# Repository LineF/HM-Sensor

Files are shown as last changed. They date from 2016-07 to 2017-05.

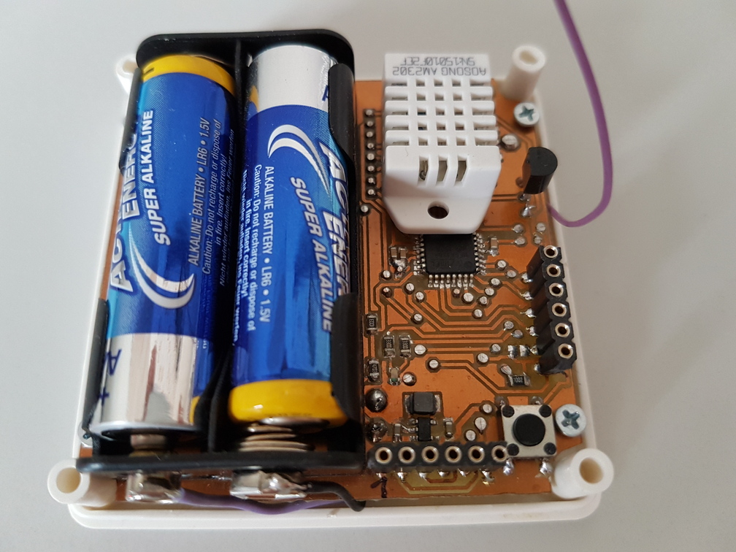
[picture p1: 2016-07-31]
Schematic/Eagle/Vorderseite.jpg

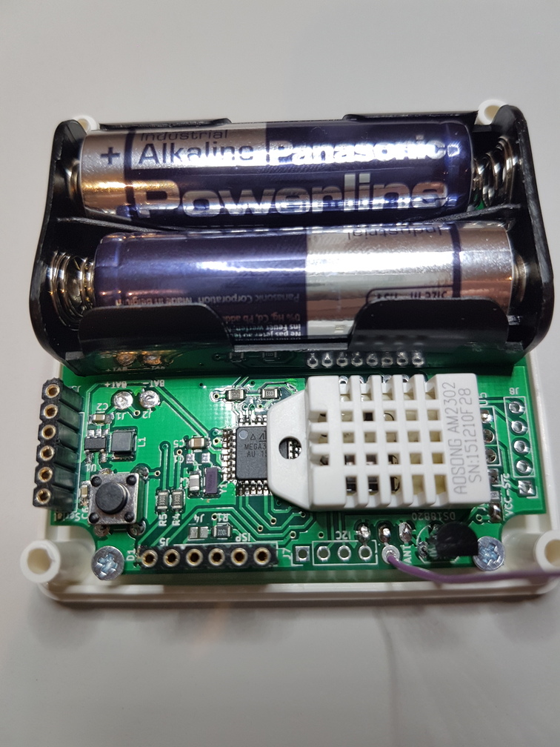
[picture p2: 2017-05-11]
Schematic/KiCad/Vorderseite fertig.jpg

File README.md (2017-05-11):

# HM-Sensor

Nachbau des "Universalsensors" von Dirk, allerdings mit anderen Sensoren.

Zum Einsatz kommen die günstigen DHT-22 und/oder DS18B20 Sensoren. 
Alternativ kann noch ein SHT-21 (sehr kompakt und genau) verwendet werden (Code hierfür allerdings nicht vorhanden)

Der Sensor verwendet als Untermodul die NewAskSin Library von Trilu. Diese habe ich für meine Bedürfnisse etwas angepaßt, wird aber zur Zeit regelmäßig mit Trilus Code aktualisiert.

**Anpassungen:**

 - Erweiterung für WeatherSensor Messages
 - weitere Verbesserungen beim Energieverbrauch
 - Stabilität beim Peering mit HM-CC-RT-DN verbessert
 - Einbau eines 32KHz Uhrenquarzes möglich - damit weitere Verbesserung der Übertragungsgenauigkeit zu einem HM-CC-RT-DN und weitere Reduktion des Stromverbrauchs
 - LED beim Senden kann abgeschaltet werden
 - OSCCAL-Register des Atmel kann remote eingestellt werden (damit kann auch ohne Quarz eine gute Genauigkeit der Taktfrequenz erreicht werden)
 - Automatische Watchdog-Kalibrierung
 - Serielle Debug-Ausgabe auf "flush" umgestellt; damit entfallen die teilweise eingebauten schlecht kalkulierbaren delays
 - Batteriemessgenauigkeit auf 1/100V erhöht (ich mag's halt genau)
 - HAVE_DATA Message-Verarbeitung: damit nimmt der Sensor auch ohne Drücken des Config-Buttons Befehle von der Zentrale bei der nächsten Temperaturübermittlung an
 - der eine oder andere Fix (teilweise von Trilu bereits eingebaut)

Schaltplan, Layout und Belichtungsplan gibt's im Unterordner Schematic.
Die erste Version wurde mit Eagle erstellt (Unterordner Eagle)
Da ich meine Platinen selber ätze, habe ich hier auf doppelseitiges Layout verzichtet - es gibt dafür ein paar Drahtbrücken.

Die zweite Version wurde mit KiCad erstellt und dann bei einem professionellen Fertiger gefertigt (Unterordner Kicad).
Da gibts auch die entsprechenden Bilder.

Achtung:
Die aktuelle Version ab Mitte Mai 2017 hat statt GDO0 jetzt GDO2 verbunden (Fehler beim Erstellen des Schaltplans).
Dies wurde aber im Communication-Modul bei den Parametern IOCFG0 und IOCFG2 entsprechend berücksichtigt.

Als Sendemodul kommt ein CC1101 auf einem günstigen Breakout-Board aus China zum Einsatz.

Entwicklungsumgebung: Atmel Studio 7.0

Der Branch "dev" ist mein aktueller Entwicklungszweig - die Version kann evtl. fehlerhaft oder gar nicht compilierbar sein.
Im Zweifelsfall bitte die Releases verwenden.

Das Release 2.0 ist das letzte stabile und basiert auf der neuen C++ Lib von Trilu (vielen Dank dafür!)

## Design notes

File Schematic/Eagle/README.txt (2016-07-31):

Achtung:

Die Layout-Files wurden nur für die eigene Platinenherstellung verwendet!
(einseitige Platine, viele Brücken)

Vor der Verwendung bei einem professionellen Platinenhersteller bitte
unbedingt Layout nochmals überprüfen (Lochdurchmesser, Abstände, etc...)

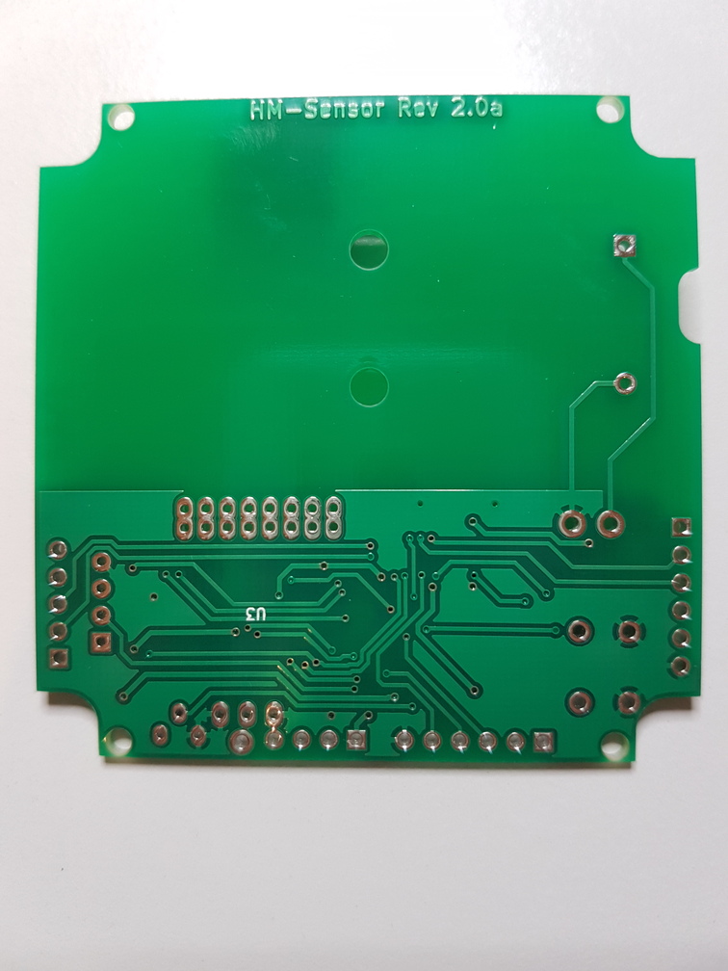
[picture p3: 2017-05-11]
Schematic/KiCad/Platine Rückseite.jpg

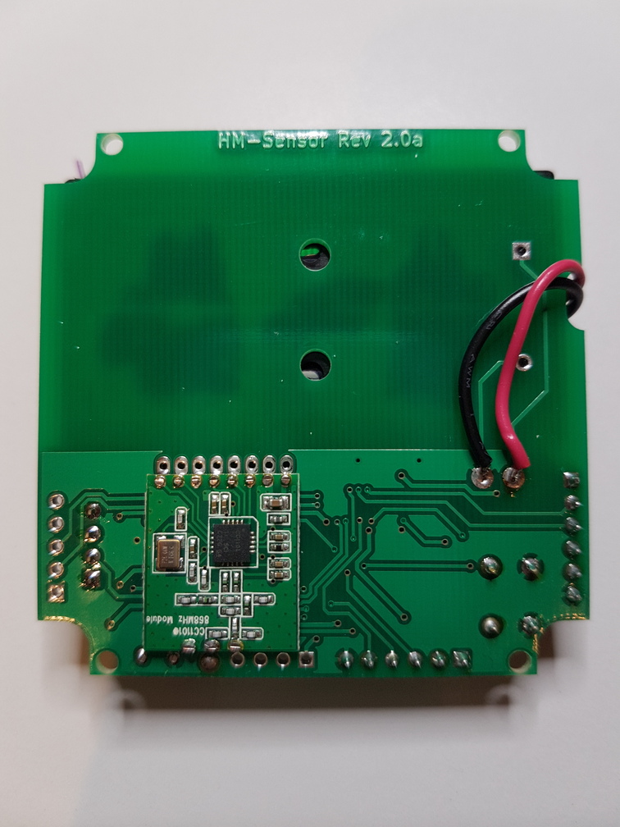
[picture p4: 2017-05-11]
Schematic/KiCad/Rückseite fertig.jpg

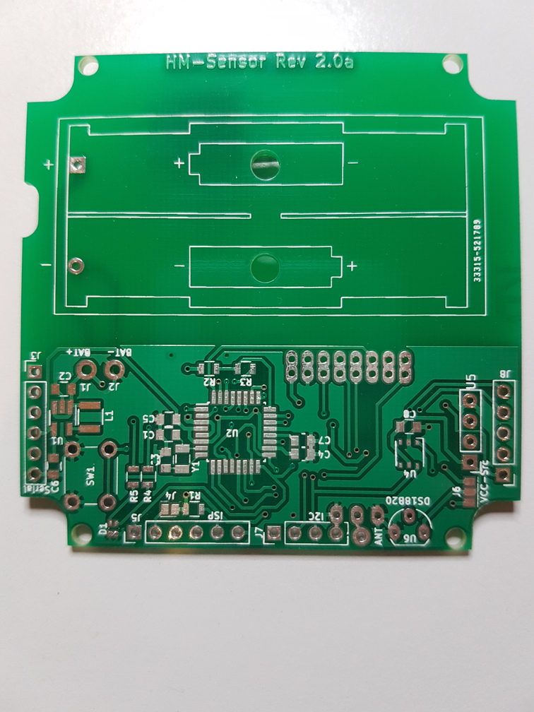
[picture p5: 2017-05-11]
Schematic/KiCad/Platine Vorderseite.jpg

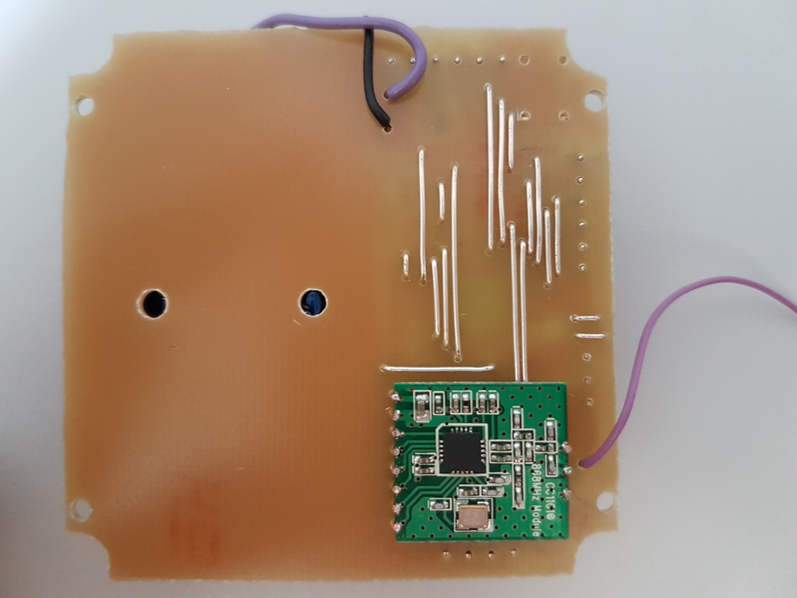
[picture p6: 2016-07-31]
Schematic/Eagle/Rückseite.jpg

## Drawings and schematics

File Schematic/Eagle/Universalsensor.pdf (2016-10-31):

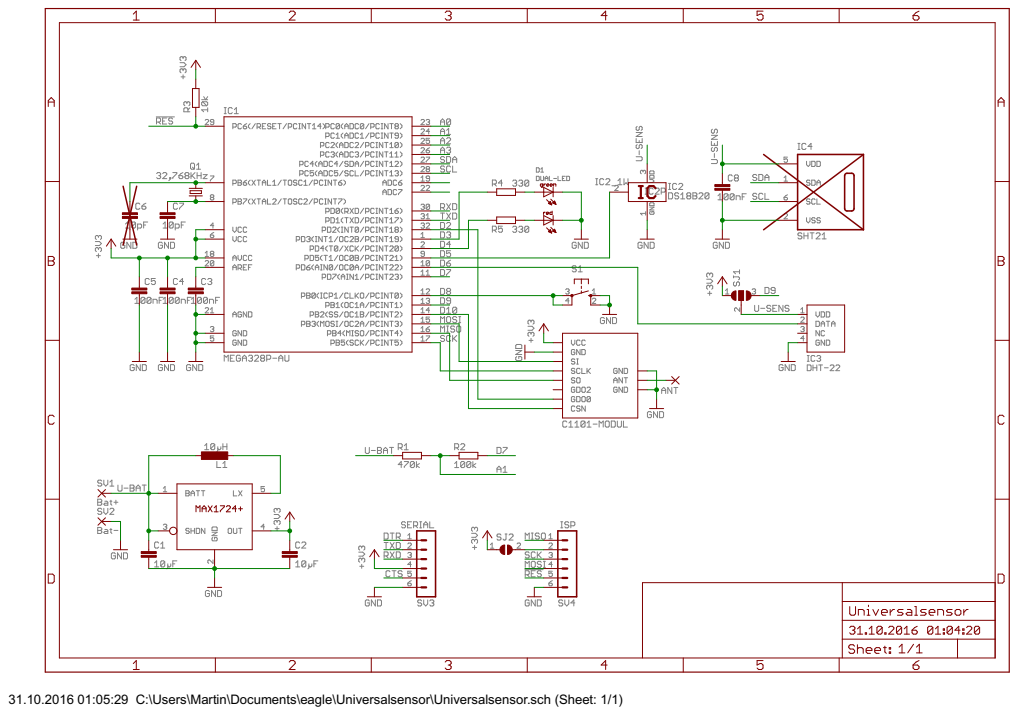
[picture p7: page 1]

31.10.2016 01:05:29 C:\Users\Martin\Documents\eagle\Universalsensor\Universalsensor.sch (Sheet: 1/1)

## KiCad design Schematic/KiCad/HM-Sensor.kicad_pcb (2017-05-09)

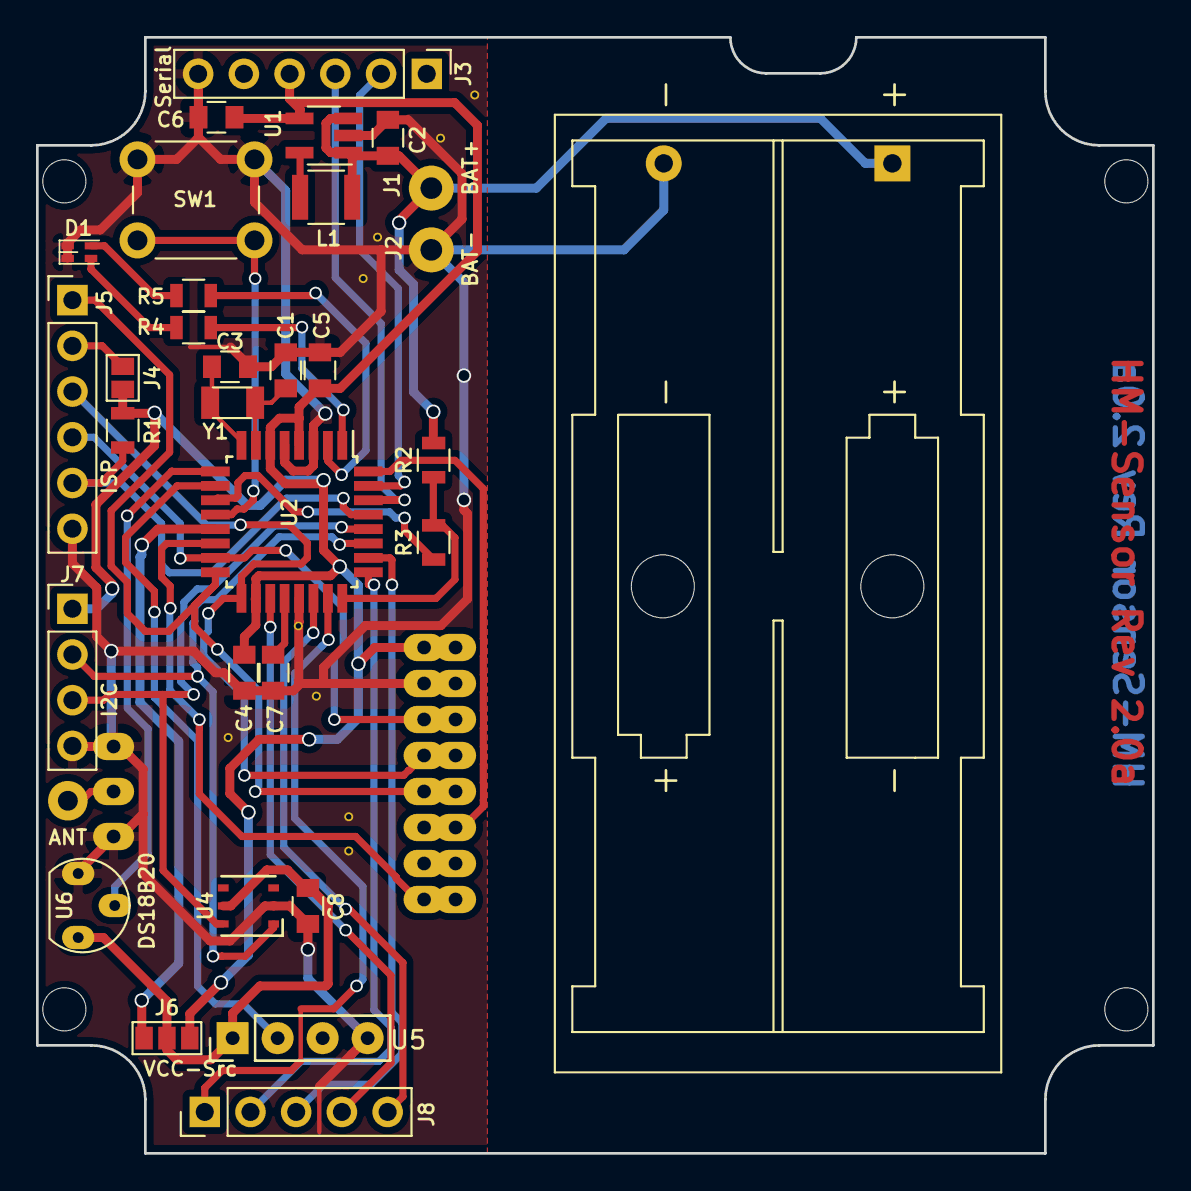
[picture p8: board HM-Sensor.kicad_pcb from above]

Board: 2 copper layers, 62.0 x 62.0 mm, 37 parts (1 on the bottom side), 35 nets.

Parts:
ANT: SolderWirePad_single_1-2mmDrill
C1, C3: 10pF; C_0805
C2, C6: 10uF; C_0805
C4, C5, C7, C8: 100nF; C_0805
D1: LED_Dual_AACC; LED-Dual-SMD-0603
H1, H2, H3, H4: MountingHole_2.5mm
J1: BAT+; SolderWirePad_single_1-2mmDrill
J2: BAT-; SolderWirePad_single_1-2mmDrill
J3: Serial; Pin_Header_Straight_1x06_Pitch2.54mm
J4: GS2
J5: ISP; Pin_Header_Straight_1x06_Pitch2.54mm
J6: VCC-Src; GS3
J7: I2C; Pin_Header_Straight_1x04_Pitch2.54mm
J8: A0-A7; Pin_Header_Straight_1x05_Pitch2.54mm
L1: 10uH; L_1210
R1: 10k; R_0805
R2: 470k; R_0805
R3: 100k; R_0805
R4, R5: 330; R_0805
REF1: Keystone_2468_2xAAA
SW1: SW_Push; SW_PUSH_6mm_h5mm
U1: MAX1724+; SOT-23-5_HandSoldering
U2: ATMEGA328P-AU; TQFP-32_7x7mm_Pitch0.8mm
U3: CC1101-Modul
U4: SHT2x; SHT21
U5: DHT22; DHT-22
U6: DS18B20; TO-92_Molded_Oval
Y1: 32.768kHz; Crystal_32KHz_CC7V_T1A

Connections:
+3V3: C4.1, C5.1, C6.1, J3.4, J4.2, J6.1, J7.1, R1.1, U1.4, U2.4, U2.6, U2.18, U3.1
//RES: J5.5, R1.2, U2.29
/A0: J8.1, U2.23
/A1: R2.1, R3.2, U2.24
/A2: J8.2, U2.25
/A3: J8.3, U2.26
/A6: J8.4, U2.19
/A7: J8.5, U2.22
/B0: SW1.1, U2.12
/B1: J6.3, U2.13
/B2: U2.14, U3.8
/D2: U2.32, U3.6
/D3: R4.2, U2.1
/D4: R5.2, U2.2
/D5: U2.9, U6.2
/D6: U2.10, U5.2
/D7: R3.1, U2.11
/MISO: J5.1, U2.16, U3.5
/MOSI: J5.4, U2.15, U3.3
/RXD: J3.3, U2.30
/SCK: J5.3, U2.17, U3.4
/SCL: J7.3, U2.28, U4.6
/SDA: J7.2, U2.27, U4.1
/TXD: J3.2, U2.31
/U-BAT: C2.1, J1.1, L1.2, R2.2, REF1.1, U1.1, U1.3
/U-Sens: C8.1, J6.2, U4.5, U5.1, U6.3
/XTAL1: C1.1, U2.7, Y1.2
/XTAL2: C3.1, U2.8, Y1.1
GND: C1.2, C2.2, C3.2, C4.2, C5.2, C6.2, C7.2, C8.2, D1.3, D1.4, J2.1, J3.6, J5.6, J7.4, REF1.2, SW1.2, U1.2, U2.3, U2.5, U2.21, U3.2, U3.9, U3.11, U4.2, U5.4, U6.1
unnamed: ANT.1, U3.10
unnamed: C7.1, U2.20
unnamed: D1.1, R4.1
unnamed: D1.2, R5.1
unnamed: J4.1, J5.2
unnamed: L1.1, U1.5

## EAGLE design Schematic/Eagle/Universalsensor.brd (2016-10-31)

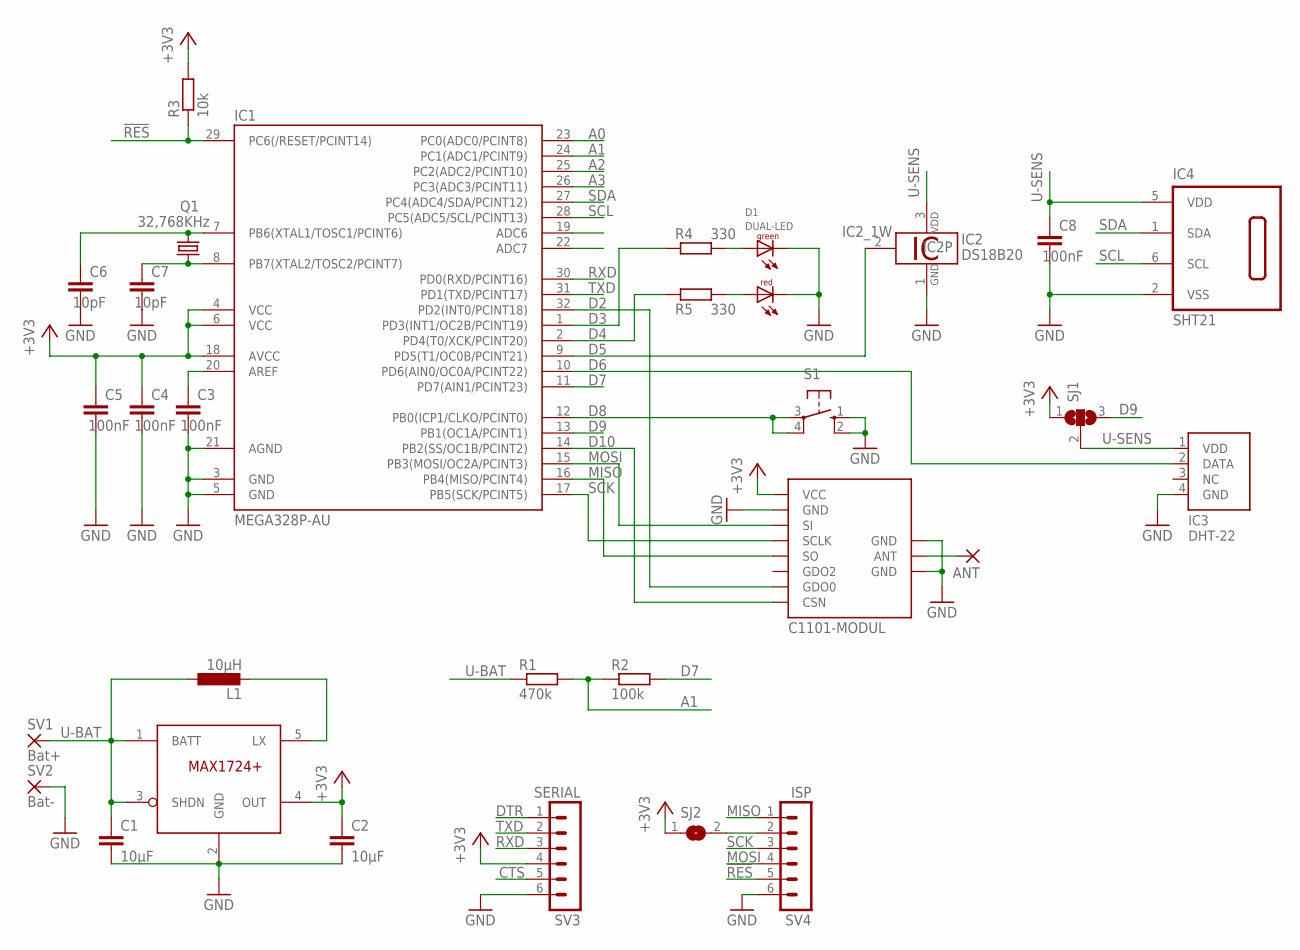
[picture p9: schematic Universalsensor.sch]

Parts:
ANT: 2,54/1,1
C1, C2: 10µF; C0603K
C3, C4, C5, C8: 100nF; C0603K
C6, C7: 10pF; C0603K
D1: DUAL-LED
IC1: MEGA328P-AU; TQFP32-08
IC2: DS18B20; TO92-
IC3: DHT-22; DHT-22-L
IC4: SHT21; DFN6/SHT
IC5: MAX1724; SOT23-5L
L1: 10µH; L3230M
Q1: 32,768KHz; OSCILLATOR_SMD
R1: 470k; R0805
R2: 100k; R0805
R3: 10k; R0805
R4, R5: 330; R0805
S1: 10-XX; B3F-10XX
SJ1: SJ2W; SJ_2
SJ2: SJ
SV1: Bat+; 2,54/1,1
SV2: Bat-; 2,54/1,1
SV3: SERIAL; MA06-1
SV4: ISP; MA06-1
U$2: C1101-MODUL; CC1101-MODUL

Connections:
!RES: IC1.29 (PC6(/RESET/PCINT14)), R3.1, SV4.5
+3V3: C2.1, C4.1, C5.1, IC1.4 (VCC), IC1.6 (VCC), IC1.18 (AVCC), IC5.4 (OUT), R3.2, SJ1.1, SJ2.1, SV3.4, U$2.VCC
A0: IC1.23 (PC0(ADC0/PCINT8))
A1: IC1.24 (PC1(ADC1/PCINT9)), R1.2, R2.1
A2: IC1.25 (PC2(ADC2/PCINT10))
A3: IC1.26 (PC3(ADC3/PCINT11))
CTS: SV3.5
D2: IC1.32 (PD2(INT0/PCINT18)), U$2.GDO0
D3: IC1.1 (PD3(INT1/OC2B/PCINT19)), R4.2
D4: IC1.2 (PD4(T0/XCK/PCINT20)), R5.2
D5: IC1.9 (PD5(T1/OC0B/PCINT21)), IC2.2 (1W)
D6: IC1.10 (PD6(AIN0/OC0A/PCINT22)), IC3.2 (DATA)
D7: IC1.11 (PD7(AIN1/PCINT23)), R2.2
D8: IC1.12 (PB0(ICP1/CLKO/PCINT0)), S1.3, S1.4 (P1)
D9: IC1.13 (PB1(OC1A/PCINT1)), SJ1.3
D10: IC1.14 (PB2(SS/OC1B/PCINT2)), U$2.CSN
DTR: SV3.1
GND: C1.2, C2.2, C3.2, C4.2, C5.2, C6.2, C7.2, C8.2, D1.P$3 (KG), D1.P$4 (KR), IC1.3 (GND), IC1.5 (GND), IC1.21 (AGND), IC2.1 (GND), IC3.4 (GND), IC4.2 (VSS), IC5.2 (GND), S1.1 (S), S1.2 (S1), SV2.1, SV3.6, SV4.6, U$2.GND@1 (GND), U$2.GND@2 (GND), U$2.GND@3 (GND)
MISO: IC1.16 (PB4(MISO/PCINT4)), SV4.1, U$2.SO
MOSI: IC1.15 (PB3(MOSI/OC2A/PCINT3)), SV4.4, U$2.SI
unnamed: IC5.5 (LX), L1.2
unnamed: C3.1, IC1.20 (AREF)
unnamed: C6.1, IC1.7 (PB6(XTAL1/TOSC1/PCINT6)), Q1.2
unnamed: D1.P$1 (AG), R4.1
unnamed: SJ2.2, SV4.2
unnamed: D1.P$2 (AR), R5.1
unnamed: C7.1, IC1.8 (PB7(XTAL2/TOSC2/PCINT7)), Q1.1
unnamed: ANT.1, U$2.ANT
RXD: IC1.30 (PD0(RXD/PCINT16)), SV3.3
SCK: IC1.17 (PB5(SCK/PCINT5)), SV4.3, U$2.SCLK
SCL: IC1.28 (PC5(ADC5/SCL/PCINT13)), IC4.6 (SCL)
SDA: IC1.27 (PC4(ADC4/SDA/PCINT12)), IC4.1 (SDA)
TXD: IC1.31 (PD1(TXD/PCINT17)), SV3.2
U-BAT: C1.1, IC5.1 (BATT), IC5.3 (SHDN), L1.1, R1.1, SV1.1
U-SENS: C8.1, IC2.3 (VDD), IC3.1 (VDD), IC4.5 (VDD), SJ1.2

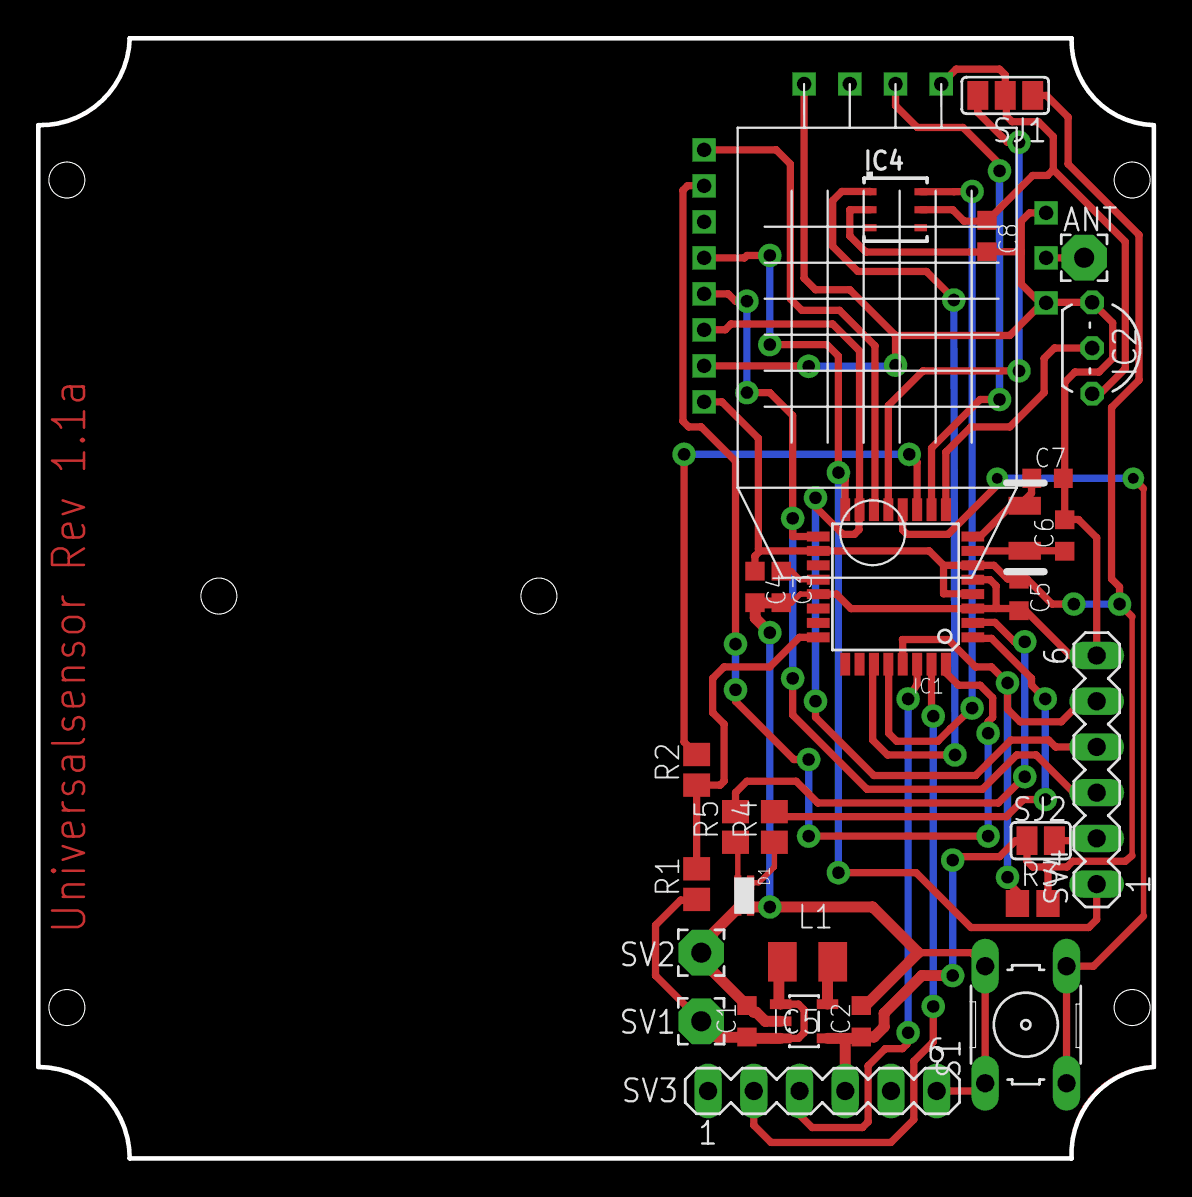
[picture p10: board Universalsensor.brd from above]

Board: 2 copper layers, 62.0 x 62.2 mm, 30 parts (1 on the bottom side), 30 nets.

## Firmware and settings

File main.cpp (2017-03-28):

/*
 * HM-Sensor.cpp
 *
 * Created: 27.12.2015 14:47:56
 * Author : Martin
 */ 

//- load library's --------------------------------------------------------------------------------------------------------
#include <Arduino.h>
#include <newasksin.h>																		// ask sin framework
#include <avr/wdt.h>
#include "00_debug-flag.h"
#include "register.h"																		// configuration sheet
#include "dht.h"
#include "OneWire.h"

//#define SER_DBG

#define DHT_PWR		9																		// power for DHT22
#define DHT_PIN		6																		// this pin DHT22 is connected to
#define OW_PIN		5																		// this pin DS18B20 is connected to


dht DHT;
OneWire OW(OW_PIN);
waitTimer thTimer;
int16_t celsius;
uint8_t transmitDevTryMax;
uint8_t ledFreqTest = 0;
uint8_t factOscCal;

void serialEvent();
void dumpEEprom();


//- arduino functions -----------------------------------------------------------------------------------------------------
void setup() {

	// - Hardware setup ---------------------------------------
	// - everything off ---------------------------------------
	
	wdt_disable();																			// clear WDRF to avoid endless resets after WDT reset
	MCUSR &= ~(1<<WDRF);																	// stop all WDT activities
	WDTCSR |= (1<<WDCE) | (1<<WDE);
	WDTCSR = 0x00;

	EIMSK = 0;																				// disable external interrupts
	ADCSRA = 0;																				// ADC off
	power_all_disable();																	// and everything else

	factOscCal = getDefaultOSCCAL();

	// enable only what is really needed
	#ifdef SER_DBG																			// some debug
		DBG_START(SER, F("SER.\n") );														// ...some debug
		DBG(SER, F("\nHB_UW_Sen_TH_Pn\n"));
		DBG(SER, F(LIB_VERSION_STRING));													// ...and some information
		DBG(SER, F("RAM free: "), freeRam(), F("\n"));										// ...and free RAM
	#endif

	// - AskSin related ---------------------------------------
	init_millis_timer2();																	// init timer2
	hm.init();																				// init the asksin framework
	sei();																					// enable interrupts
 
	// - user related -----------------------------------------
	#ifdef SER_DBG
		DBG(SER, F("HMID: "), _HEX(dev_ident.HMID,3), F(", MAID: "), _HEX(dev_operate.MAID,3), F("\n\n"));	// some debug
	#endif
}


//- user functions --------------------------------------------------------------------------------------------------------
void initTH(uint8_t channel) {																// init the sensor
	
	pinMode(DHT_PWR, OUTPUT);
	
	#ifdef SER_DBG
		DBG(SER, F("init th: cnl: "), channel, F("\n"));
	#endif
}

// this is called when HM wants to send measured values to peers or master
// due to asynchronous measurement we simply can take the values very quick from variables
void measureTH(uint8_t channel, cm_thsensor::s_sensVal *sensVal) {
	int16_t t;
	
	//DBG(SER, "msTH DS-t: ", celsius, F(" "), _TIME, F("\n"));
	// take temp value from DS18B20
	t = celsius / 10;
	((uint8_t *)&(sensVal->temp))[0] = ((t >> 8) & 0x7F);									// battery status is added later
	((uint8_t *)&(sensVal->temp))[1] = t & 0xFF;
	
	//DBG(SER, "msTH t: ", DHT.temperature, ", h: ", DHT.humidity, ' ', _TIME, F("\n"));
	// take humidity value from DHT22
	sensVal->hum = DHT.humidity / 10;
	// fetch battery voltage
	t = bat.get_volts();
	((uint8_t *)&(sensVal->bat))[0] = t >> 8;
	((uint8_t *)&(sensVal->bat))[1] = t & 0xFF;
}

void cnl0Change(void) {
	
	// set lowBat threshold
	bat.set(3600000, *cmm[0]->list[0]->ptr_to_val(REG_CHN0_LOW_BAT_LIMIT_TH)*10);			// check voltage every hour

	// handle r/o factory osccal register
	if (*cmm[0]->list[0]->ptr_to_val(REG_CHN0_FACT_OSCCAL) != factOscCal)
	{
		uint8_t a[2];
		a[0] = REG_CHN0_FACT_OSCCAL;
		a[1] = factOscCal;
		DBG(SER, F("main: setting factOscCal register back to default: "), _HEX(a, 2), F("\n"));
		cmm[0]->list[0]->write_array(a, 2);
	}
	
	// set OSCCAL frequency
	if (uint8_t oscCal = *cmm[0]->list[0]->ptr_to_val(REG_CHN0_OSCCAL)) {
		DBG(SER, F("will set OSCCAL: old="), OSCCAL, F(", new="), oscCal, F("\n"));
		// Attention: your controller my have other factory calibration !!
		// If you are unsure about the internal RC-frequency of your chip then use factory default (oscCal-Reg = 0)
		// my chip: 1kHz - 8A=994Hz, 8B=998,4Hz, 8C=1001,6Hz, 8E=1010Hz
		// frequency measured with help of millis-ISR (toggling LED port and measuring frequency on it)

		OSCCAL = oscCal;
	} else {
		DBG(SER, F("will set default OSCCAL: "), factOscCal, F("\n"));
		OSCCAL = factOscCal;
	}
	#ifndef TIMER2_LOW_FREQ_OSC
		calibrateWatchdog();
	#endif

	// if burstRx is set ...
	if (*cmm[0]->list[0]->ptr_to_val(REG_CHN0_BURST_RX)) {
		DBG(SER, F("PM=onradio\n"));
		pom.setMode(POWER_MODE_WAKEUP_ONRADIO);											// set mode to wakeup on burst
	} else {																				// no burstRx wanted
			DBG(SER, F("peers: "), cmm[1]->peerDB.used_slots(), F("\n"));
			if (cmm[1]->peerDB.used_slots())
			{
				DBG(SER, F("PM=250ms\n"));
				pom.setMode(POWER_MODE_WAKEUP_250MS);										// set mode to awake every 250 msecs
			}
			else
			{
				DBG(SER, F("PM=8000ms\n"));
				pom.setMode(POWER_MODE_WAKEUP_8000MS);										// set mode to awake every 250 msecs
			}
	}

	// check if frequency test output is wanted
	ledFreqTest = ((*cmm[0]->list[0]->ptr_to_val(REG_CHN0_LED_MODE) & 0xC0) == 0xC0);

	// fetch transmitDevTryMax
	if ((transmitDevTryMax = *cmm[0]->list[0]->ptr_to_val(REG_CHN0_TRANS_DEV_TRY_MAX)) > 10)
		transmitDevTryMax = 10;
	else if (transmitDevTryMax < 1)
		transmitDevTryMax = 1;
}

// this is called regularly - real measurement is done here
void measure() {
	enum mState {mInit, mWait, mPwrOn, mStartDS};
	static mState state = mWait;

	if (!thTimer.done())
		return;
		
	if (state == mInit) {																	// wait some time till next measurement
		thTimer.set(88000);																	// measurement every 90 secs
		state = mWait;
	}
	else if (state == mWait) {																// power on sensor and wait 1 sec
		thTimer.set(1000);
		pinMode(OW_PIN, INPUT_PULLUP);
		digitalWrite(DHT_PWR, 1);															// power on here

		state = mPwrOn;
		#ifdef SER_DBG
			//dbg << "power on Sensor" << ' ' << _TIME << '\n';
		#endif
	}
	else if (state == mPwrOn) {																// now start measurement on DS18B20 and wait another second
		thTimer.set(1000);
		uint8_t rc = OW.reset();															// attention - OW device get ready to communicate!
		OW.skip();																			// skip rom selection - we have only one device attached
		OW.write(0x44);																		// start conversion
		#ifdef SER_DBG
			//dbg << "rc: " << rc << _TIME << '\n';
		#endif
		state = mStartDS;
	}
	else if (state == mStartDS)	{															// get results here and switch off sensor
		DHT.read22(DHT_PIN);																// read DHT22
		#ifdef SER_DBG
			dbg << "t: " << DHT.temperature << ", h: " << DHT.humidity << ' ' << _TIME << '\n';
		#endif
		
		OW.reset();																			// attention - get ready to read result from DS18B20
		OW.skip();																			// no rom selection
		OW.write(0xBE);																		// read temp from scratchpad
		int16_t t = ((int32_t)(OW.read() | (OW.read() << 8)) * 100) >> 4;					// we need only first two bytes from scratchpad
		if (t != 8500)
			celsius = t;
	
		#ifdef SER_DBG
			dbg << "DS-t: " << celsius << ' ' << _TIME << '\n';
		#endif

		digitalWrite(DHT_PWR, 0);															// power off sensor
		pinMode(OW_PIN, INPUT);
		pinMode(DHT_PIN, INPUT);
		
		#ifdef SER_DBG
			//dbg << "power off Sensor" << ' ' << _TIME << '\n';
		#endif
		state = mInit;
	}
}


int main(void)
{
	// Arduino init: initializes timers etc.
	// not needed here - all timers/functions initialized by own functions
	// init();
	
	// Initialize all functions and pins
	setup();
	
    /* Replace with your application code */
    while (1) 
    {
			// - AskSin related ---------------------------------------
			hm.poll();																		// poll the homematic main loop

			// - user related -----------------------------------------
#ifdef SER_DBG
			serialEvent();
#endif
			measure();
    }
}

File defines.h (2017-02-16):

/*
 * defines.h
 *
 * Created: 25.01.2017 22:27:26
 *  Author: Martin
 */ 


#ifndef DEFINES_H_
#define DEFINES_H_

// Register in Channel 0
#define	REG_CHN0_BURST_RX					1							// Register 1.0 / 1.0: 0=burstRx off, otherwise on
#define	REG_CHN0_LED_MODE					5							// Register 5.6 / 0.1: bit 6 LED mode (on/off)
#define	REG_CHN0_PAIR_CENTRAL				10							// Register 10.0 / 3.0: 3 byte HMID
#define	REG_CHN0_LOW_BAT_LIMIT_TH			18							// Register 18.0 / 1.0: in 1/10 volts
#define	REG_CHN0_TRANS_DEV_TRY_MAX			20							// Register 20.0 / 1.0: 1-10, maxRetryCount
#define	REG_CHN0_OSCCAL						35							// Register 35.0 / 1.0: 0=default, other=ATMEL:OSCCAL
#define	REG_CHN0_FACT_OSCCAL				36							// Register 36.0 / 1.0: readonly register - do not set
#define	REG_CHN0_CYCL_MSG_OFFSET			37							// Register 37.0 / 1.0: cyclic Message Offset in 50ms steps (-100..100)

#define	TIMER2_LOW_FREQ_OSC												// use 32KHz crystal

#endif /* DEFINES_H_ */

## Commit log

2016-06-26 added subrepo NewAskSin, fix osccal settings
    [main.cpp]
2016-07-08 more power savings
2016-07-31 more schematic files added
    [Universalsensor.brd, Universalsensor.sch]
2016-10-07 some work, but reading registers doesn't work
    [main.cpp]
2016-10-08 fix minor typos, add extended debug console
    [main.cpp]
2016-10-16 new schematic for low freq crystal oscillator and sht21
    [Universalsensor.brd, Universalsensor.sch]
2016-10-29 changes to support low frequency oscillator
    [main.cpp]
2016-10-31 schematic changed - only one crystal load capacitor needed, crystal doc added
    [Universalsensor.brd, Universalsensor.sch]
2016-11-05 revert to 250ms mode
    [main.cpp]
2016-12-26 fix compilation errors due to merge, fix project member files
    [main.cpp]
2017-01-04 fix 85C and change in filenames
    [main.cpp]
2017-02-12 add configurable cyclicMessageOffset, r/o factory osccal and frequency test led
2017-02-16 change power_modes, change factOscCal handling, change debugging
2017-02-22 changes for new battery oversampling
2017-04-22 added kicad schematic files
    [HM-Sensor.kicad_pcb, HM-Sensor.sch]
2017-04-22 pcb routing complete
    [HM-Sensor.kicad_pcb]
2017-04-23 went to production
    [HM-Sensor.kicad_pcb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]
2017-04-26 better ground layout
    [HM-Sensor.kicad_pcb]
2017-05-11 change hmid and serial for new test device
2017-05-11 restructure schematic file tree, add pictures
    [Universalsensor.brd, Universalsensor.sch]

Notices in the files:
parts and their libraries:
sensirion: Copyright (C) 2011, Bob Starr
